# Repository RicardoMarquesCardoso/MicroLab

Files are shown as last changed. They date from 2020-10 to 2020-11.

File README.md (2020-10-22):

# MicroLab
The Microlab project describes how to build a simple and inexpensive system for the opperation of microfluidic devices. The system consists of four syringe pumps and a microscope. To opperate this peripherals, software was also developed. 

## System Overview 

<p align="center">
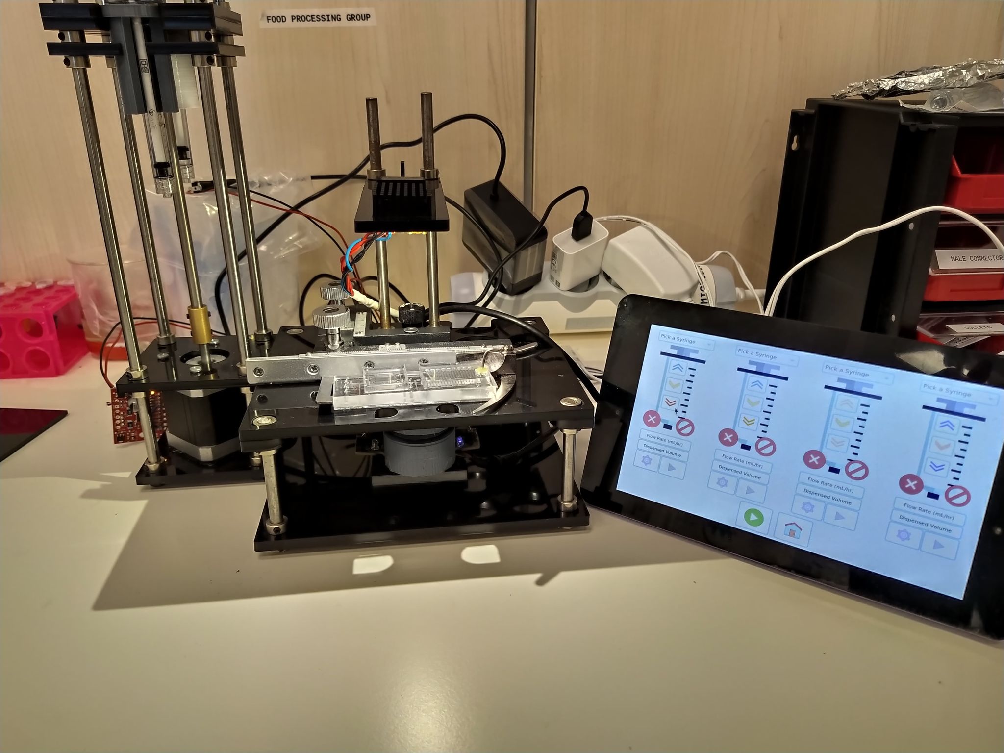
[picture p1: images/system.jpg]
  
</p>

The system consists of:
* [Syringe Pump](Microlab/SyringePump) 
* [Microscope](https://github.com/RicardoMarquesCardoso/MicroLab/tree/main/Microscope) 
* [Software](Microlab/Software) 

**The peripherals were developed using 3D printing techniques and laser cutting. Both methods are required in order to build the system**

## Contents

### Syringe Pump

* CAD drawings
* Bill of materials
* How to build 
* Microcontroller Code

### Microscope

* Bill of materials
* How to build 

### Software

* Raspberry Pi + Touchscreen
* How to install Windows, Mac, Linux
* Basic Guide

## About

This project was developed by me, Ricardo Cardoso, in collaboration with the International Iberian Nanotechnology Laboratory for my master thesis in Biomedical Engineering at the University of Porto .

This project is inspired in solutions developed by [Martin Fischlechner, Jonathan West and Klaus-Peter Zauner](https://dropletkitchen.github.io/pages/projects.html) and by [Patcherlab](https://pachterlab.github.io/poseidon/).

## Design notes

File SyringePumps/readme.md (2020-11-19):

# Syringe Pump

### Introduction

The goal is to develop a low-cost, easy to build syringe pump suitable for the operation of microfluidic devices. This solution is heavily influenced by the one presented by [DropletKitchen](https://github.com/DropletKitchen/pumpsn17). 

The developed syringe pumps tries to introduce two main features to the other available noncommercial solutions:

* Dispense two syringes with a single device;
* Possibility to operate in the vertical position;

Step resolution : 0.04 nm/µstep
Size : 7cm x 7cm x 30cm
Price : 110 €

<p align="center">
  
</p>

### Materials and tools

Besides all required [materials](#bill-of-materials), to replicate this project you will need access to a: 

* Laser Cutter machine;
* 3D printing machine; 
* Welding machine;

### About

This project was developed at the International Iberian Nanotechnology Laboratory by Ricardo Cardoso and supervised by Miguel Xavier,Ph.D. and researcher at INL. 
The main inspiration for this project was the [DropletKitchen's solution](https://dropletkitchen.github.io/index.html). Please go and review their project as a lot of information is complementary to this one!

## Stepper Motor + LeadScrew

## Driver

## Structure

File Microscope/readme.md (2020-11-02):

# Microscope

### Introduction

This describes a portable, low-cost, easy to build microscope suitable for the operation of microfluidic devices. 
The microscope consists of three main parts: 

* [Camera](#camera)
* [Light](#light)
* [Structure](#structure)

<p align="center">
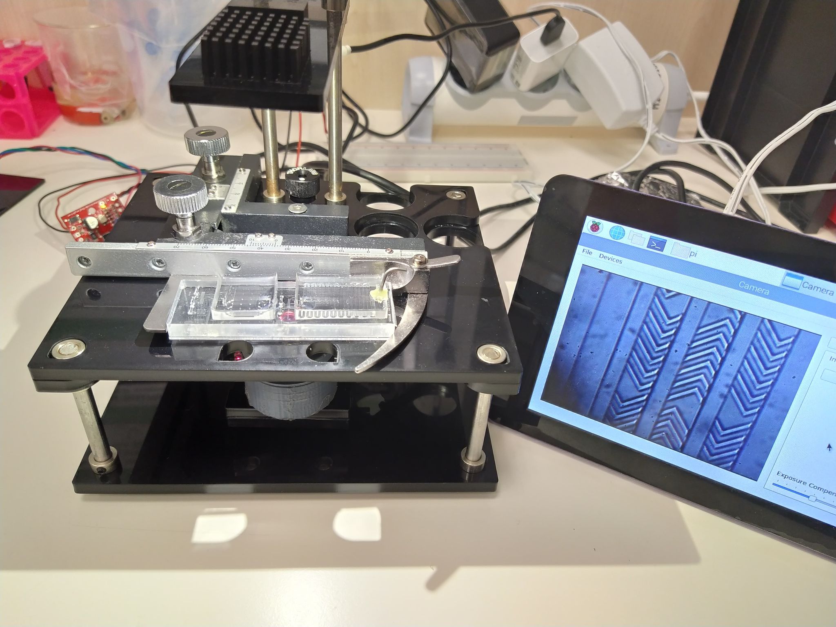
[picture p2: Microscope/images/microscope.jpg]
  
</p>

### Materials and tools

Besides all required [materials](#bill-of-materials), to replicate this project you will need access to a: 

* Laser Cutter machine;
* 3D printing machine; 
* Welding machine;

### About

This project was developed at the International Iberian Nanotechnology Laboratory by Ricardo Cardoso and supervised by Miguel Xavier,Ph.D. and researcher at INL. 
The main inspiration for this project was the [DropletKitchen's solution](https://dropletkitchen.github.io/index.html). Please go and review their project as a lot of information is complementary to this one!

## Camera

Shows you how to choose a suitable camera and how to alter it.

You will need some basic tools to take apart the camera and acess to a **3D printer**.

### Choosing a camera 

Based on previous studied open-source solutions, three main alternatives to a commercial microscope were identified: a USB microscope, a camera module or an altered webcam.
A few options were considered:

<p align="center">
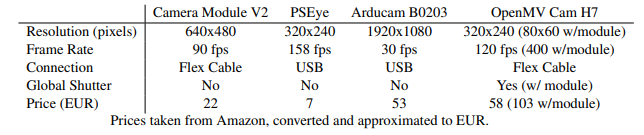
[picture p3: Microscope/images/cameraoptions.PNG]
  
</p>

The camera module OpenMV Cam H7 has a global shutter module that costs around 45 EUR.
Even though global shutter cameras are useful in some microfluidic applications, they are less available and have higher prices. More economical options exist such as the Sony 811 700TVL. However, instead of USB interface, these cameras have Analog High Definition (AHD) interface. The Raspberry Pi Camera Module V2 has interesting specs and a relatively low price; however the connection not being USB is a major disadvantage. The connection is made specifically for the Raspberry Pi through flat cable, which is not convenient for connecting and disconnecting regularly. Other camera modules exist, such as the Arducam B0203 that connect through USB; however they tend to be expensive.
For my requirements I chose the PlayStationEye camera for four main reasons: availability, cost, performance and connectivity. The main disadvantage is that additional drivers (CLEYE drivers and SDK) are required for the PS Eye to work on Windows, as well as for Mac OS.

### PSEye  

The PSEye fullfills all the requirements while being cheap and widely available. To transform this webcam into a microscope we need to simply invert the lens, going from concave to convex. An example on how to easily do this is found in [Hacketeria](https://www.hackteria.org/projects/ps3-eye-diy-microscopy-hack/). 

Two variables are essential for any basic microscope, focusing and zooming. Focusing is regulated by the distance between the lens and the sample, zooming by the distance between the lens and the CMOS. To allow for zooming, I designed a 3D printed part that allows the user to change the distance of the lens to the CMOS ([Part1](https://github.com/RicardoMarquesCardoso/MicroLab/blob/main/Microscope/Parts/%5BPSeye%5D%201.SLDPRT);[Part2](https://github.com/RicardoMarquesCardoso/MicroLab/blob/main/Microscope/Parts/%5BPSeye%5D%202.SLDPRT)). 

**Missing pic of finished part**

## Light

An independent circuit is responsible for illumination. One of the requirements for this microscope was that it should produce quality images even in total darkness. As so, a high-power LED was incorporated into the device. 

You will need:

* [LED](https://pt.farnell.com/opulent/rebel-star-nw100/led-luxeon-rebel-star-nw100/dp/2115404);
* [LED Driver](https://www.digikey.pt/product-detail/en/recom-power/RCD-24-0.70-W/945-1125-ND/2256305);
* [Potentiometer (10kOhm)](https://www.amazon.com/Slide-Potentiometer-Single-Linear-Taper/dp/B00L9YDRU6);
* Wires;
* Welding machine;
* Male USB connector;

The circuit is very simple and it should take less than an hour to build. I advise you to check if the circuit is working (without welding) before mounting it onto the microscope structure. 

<p align="center">
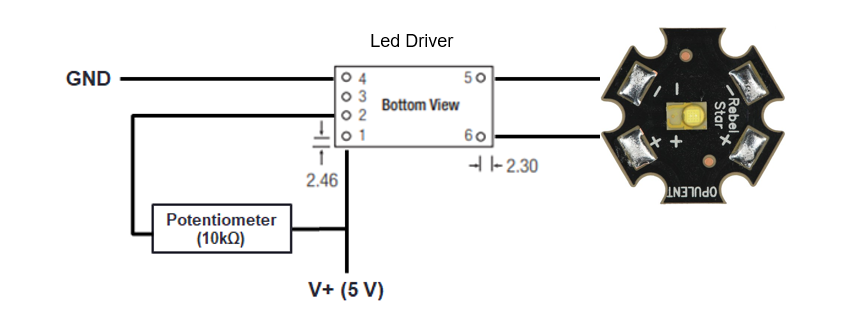
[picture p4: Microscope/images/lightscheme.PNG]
  
</p>

To simplify the powering of the circuit, a male USB connector is added to the end of the circuit. This allows the microscope to be powered by a common powerbank, avoiding the need for another electrical outlet and making the microscope portable.

<p align="center">
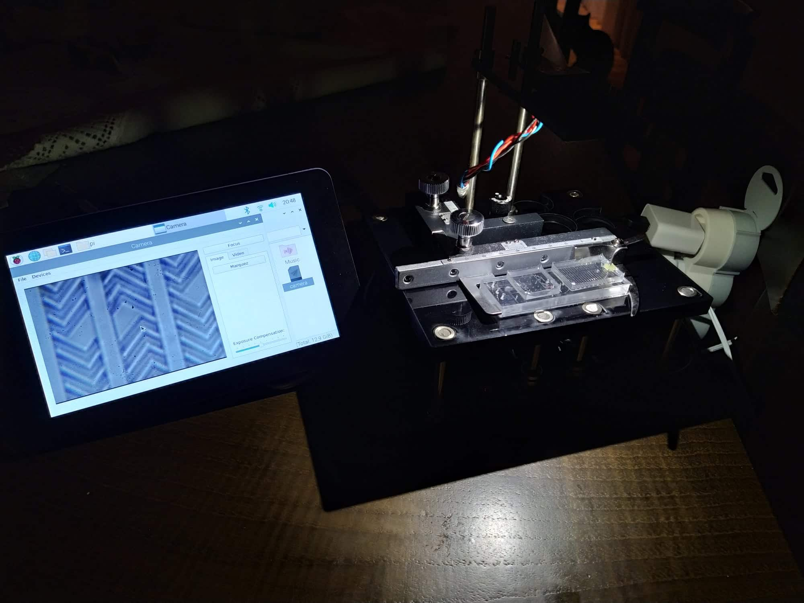
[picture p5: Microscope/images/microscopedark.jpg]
  
</p>

**Missing pic of finished part**

## Structure

You will need:

* 1x A3 Acrylic sheets (5mm);
* 4x Steel Bar 6x70 mm;
* 2x Steel Bar 6x130 mm;
* 30x Collets 6mm;
* Laser Cutter;

Before cutting any piece in acrylic [check](https://github.com/RicardoMarquesCardoso/MicroLab/tree/main/Microscope/Parts) the measurements and test them with your machine setup. 

If it's the first time building the device I would suggest to print each part separately. 

### Step 1

1. Print the two top parts of the microscope ([Part1](https://github.com/RicardoMarquesCardoso/MicroLab/blob/main/Microscope/Designs/%5BTop%5DPart1.DXF),[Part2](https://github.com/RicardoMarquesCardoso/MicroLab/blob/main/Microscope/Designs/%5BTop%5DPart2.DXF)
2. Glue them together using double sided tape.
3. Place a collet in the tip of each 6x70mm steel bar and slide them into the respective holes. Then using another collet pin the steel bars. 
4. Screw the microscope stage in place.

<p align="center">
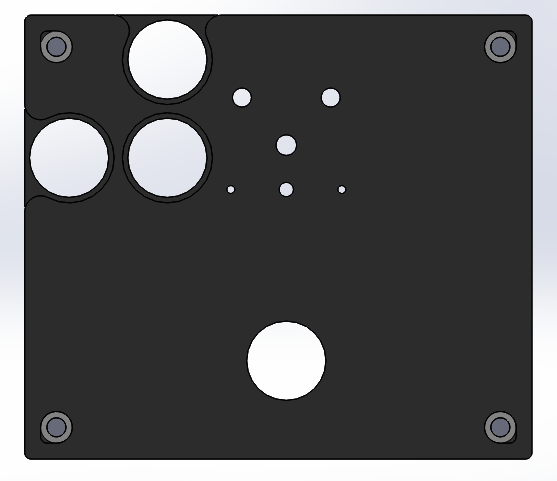
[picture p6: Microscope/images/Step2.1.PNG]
  
</p>

<p align="center">
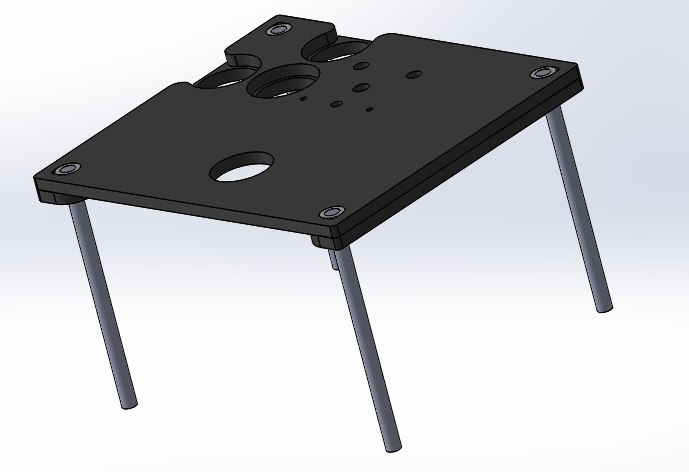
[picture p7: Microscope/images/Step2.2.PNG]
  
</p>

### Step 2

1. Print the parts that will hold the camera ([Top1](https://github.com/RicardoMarquesCardoso/MicroLab/blob/main/Microscope/Designs/%5BMovingPiece%5DTop1.DXF),[Top2](https://github.com/RicardoMarquesCardoso/MicroLab/blob/main/Microscope/Designs/%5BMovingPiece%5DTop2.DXF),[Bottom](https://github.com/RicardoMarquesCardoso/MicroLab/blob/main/Microscope/Designs/%5BMovingPiece%5DBottom.DXF))
2. Glue the top parts to the bottom using double sided tape.
3. Put the linear bearings into the respective holes. They should be very tight to impossibilitate the acrylic from sliding.
4. Screw the modified PSEye in place. 
5. Place the nut and the screw.
6. With the microscope in upright position place the 2 support bars and pin them in place. 
7. Place the mounted camera part into place.

<p align="center">
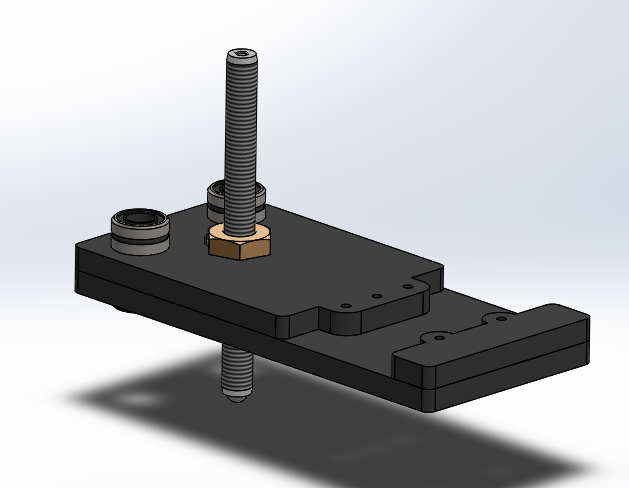
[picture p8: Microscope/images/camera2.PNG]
  
</p>

<p align="center">
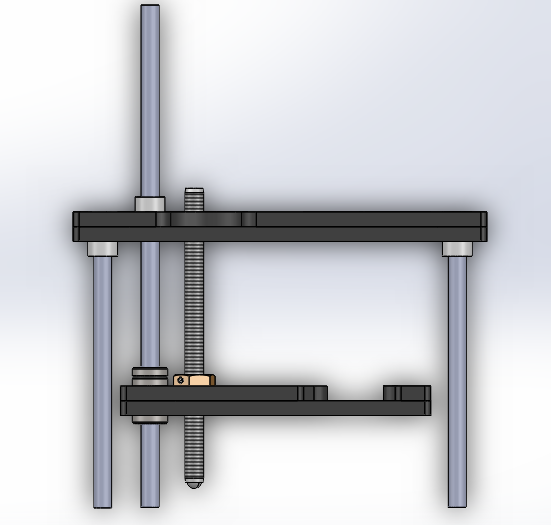
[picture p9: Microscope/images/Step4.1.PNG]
  
</p>

### Step 3

1. Print and place the bottom part and LED parts.

<p align="center">
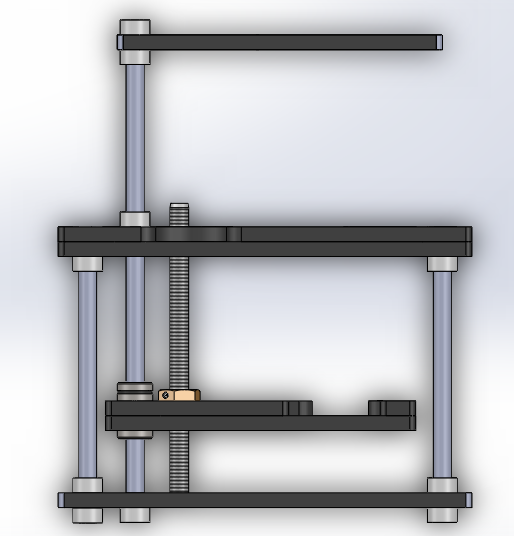
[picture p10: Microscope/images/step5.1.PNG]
  
</p>

## Results

<p align="center">
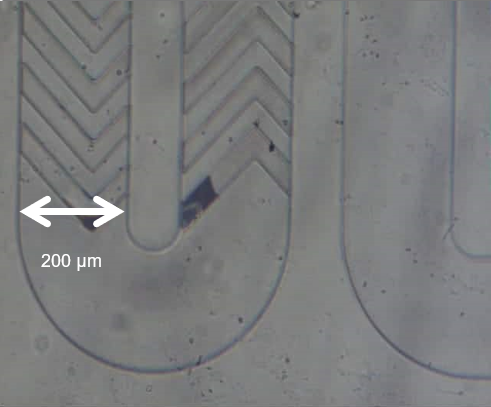
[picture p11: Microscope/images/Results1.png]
  
</p>

## Bill of materials 

<p align="center">
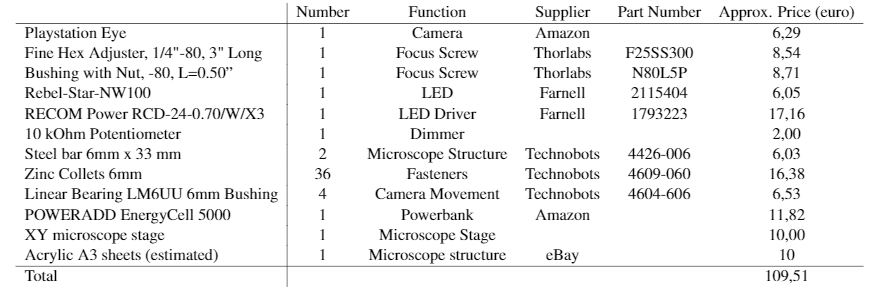
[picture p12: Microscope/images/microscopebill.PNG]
  
</p>

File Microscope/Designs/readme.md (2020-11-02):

# Microscope Parts

**Before cutting any piece in acrylic check the measurements and test them with your machine setup.**

To easy the proccess, each 'hole' in the acrylic is highlighted with a certain color:

- #c5f015- Measurements that don't need much attention;
- #1589F0- Measurements that need some checking since some precision is required;
- #f03c15- Measurements that need to be thoroughly checked, a lot of precision is required;

## Top 

<p align="center">
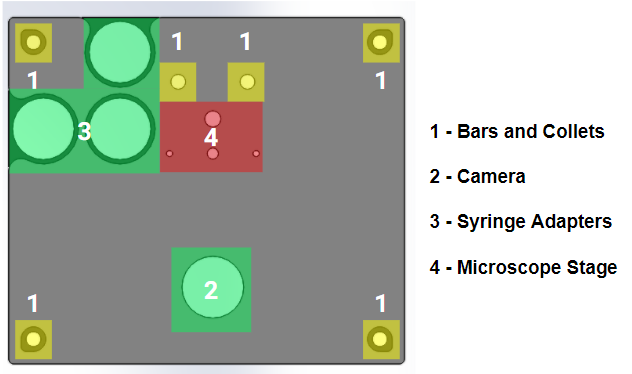
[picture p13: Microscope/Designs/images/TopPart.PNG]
  
</p>

**Keep in mind that your microscope stage may be different**

## Bottom

<p align="center">
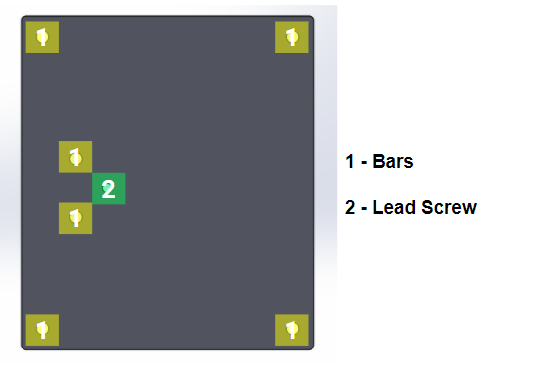
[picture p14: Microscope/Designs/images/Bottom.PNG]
  
</p>

**Lead Screw hold should be smaller than the point of the lead screw.** 

## Light 

<p align="center">
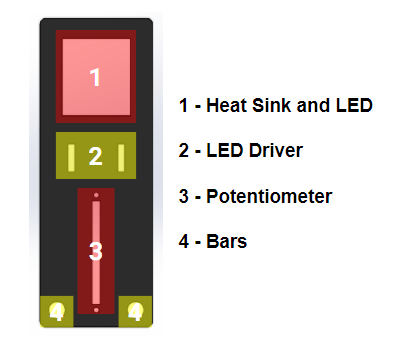
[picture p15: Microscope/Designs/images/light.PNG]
  
</p>

**Put each component in the respective place and then weld the circuit.**

## Camera

<p align="center">
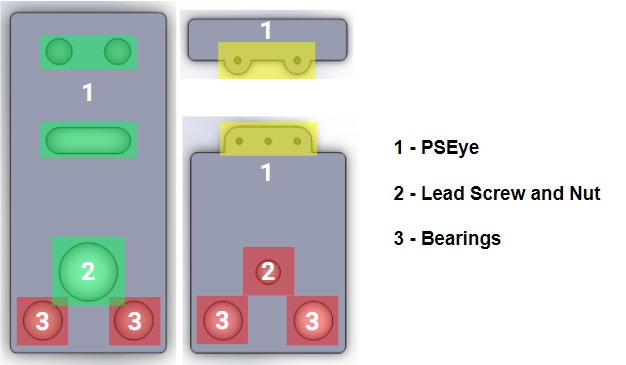
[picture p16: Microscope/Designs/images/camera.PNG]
  
</p>

**This is designed to hold a PSEYE, if you chose a different camera please alter the respective dimensions.**

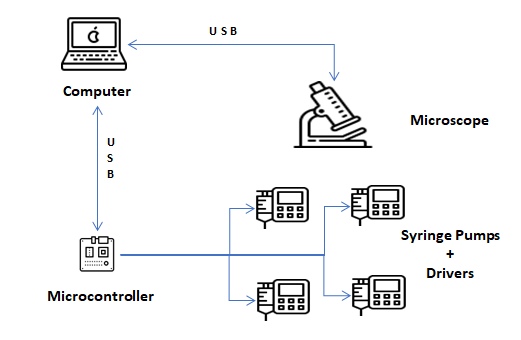
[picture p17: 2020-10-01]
images/overallsystem2.PNG

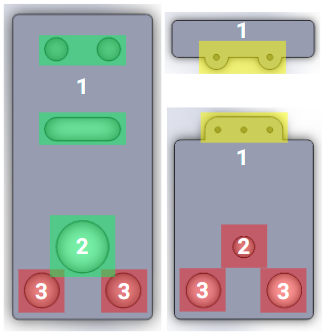
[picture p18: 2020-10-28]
Microscope/images/movingpart.PNG

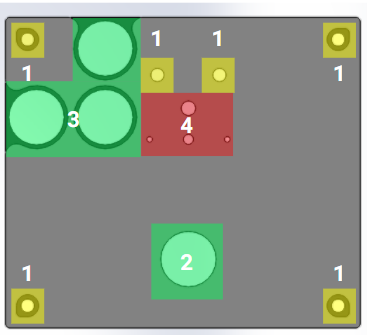
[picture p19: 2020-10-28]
Microscope/images/TopPart.PNG

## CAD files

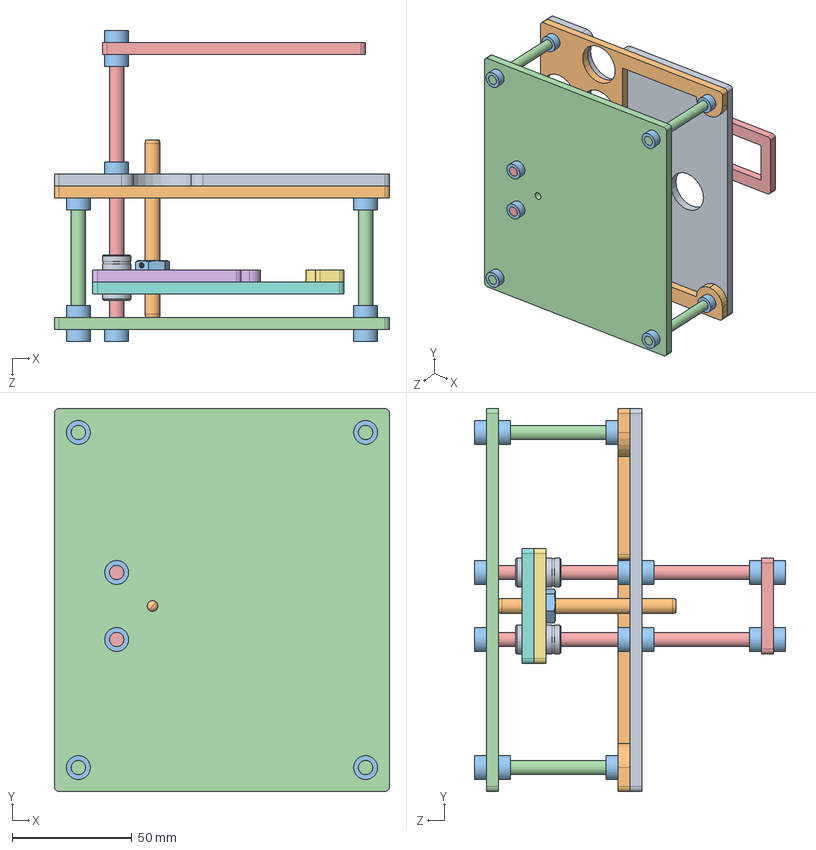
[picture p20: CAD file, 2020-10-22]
Microscope/Parts/Microscope.SLDASM
140.0 x 160.0 x 130.0 mm
[Top] Part1
[Top] Part2
Collets x 27
Bar7cm x 4
Bar13cm x 2
[MovingPiece] top1
[MovingPiece] top2
[MovingPiece] bottom
Bearing (LM6UU) x 2
Screw (F25SS300)
Nut (N80L5P)
BottomPart
Light

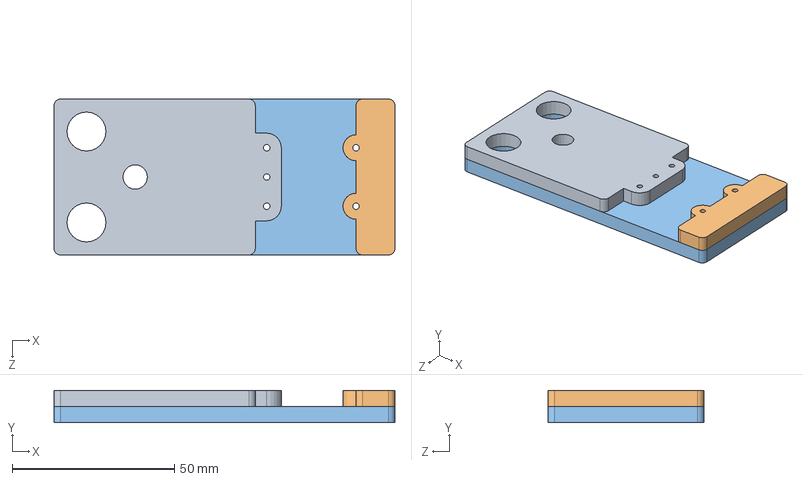
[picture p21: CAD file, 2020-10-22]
Microscope/Parts/[MovingPiece]Assembly.SLDASM
105.0 x 10.0 x 48.0 mm
[MovingPiece] top1
[MovingPiece] top2
[MovingPiece] bottom

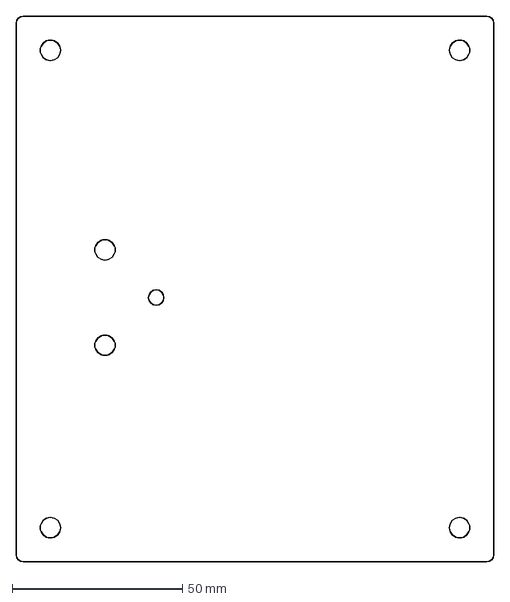
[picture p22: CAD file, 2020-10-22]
Microscope/Designs/BottomPart.DXF
140.0 x 160.0 mm

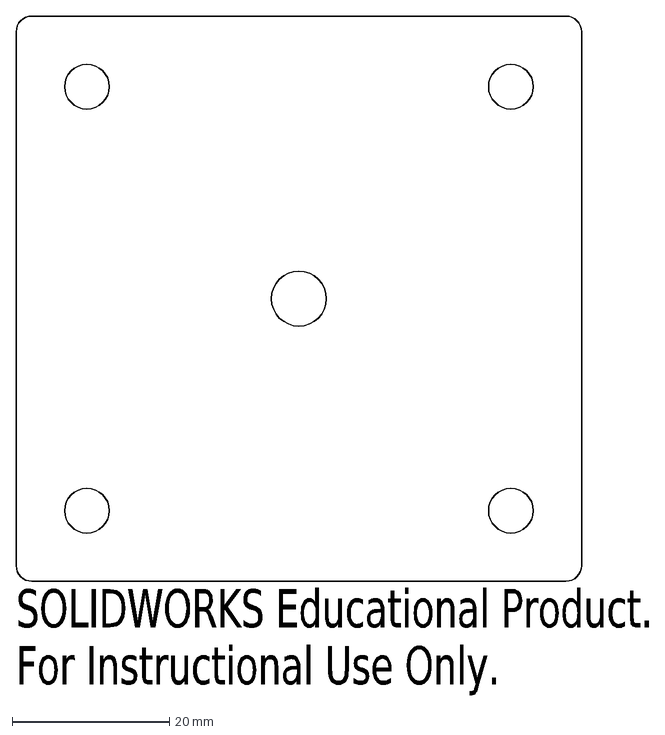
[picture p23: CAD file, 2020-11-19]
SyringePumps/Designs/TopCover.DXF
SOLIDWORKS Educational Product.
For Instructional Use Only.

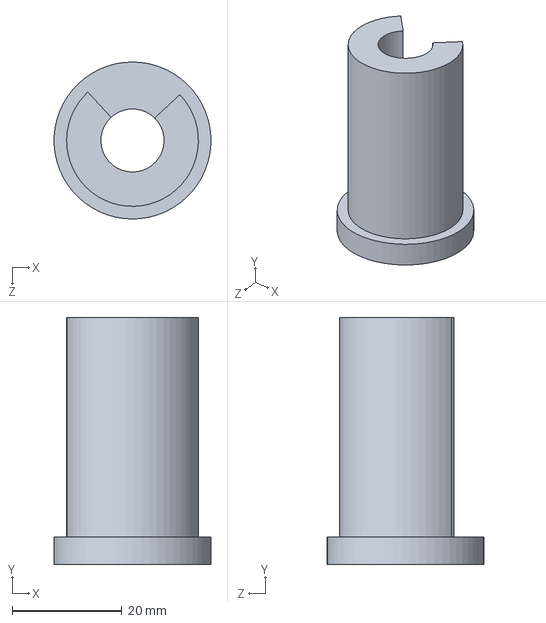
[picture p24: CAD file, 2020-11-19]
SyringePumps/Parts/Adapters/11.5mm.SLDPRT
28.6 x 45.0 x 28.6 mm

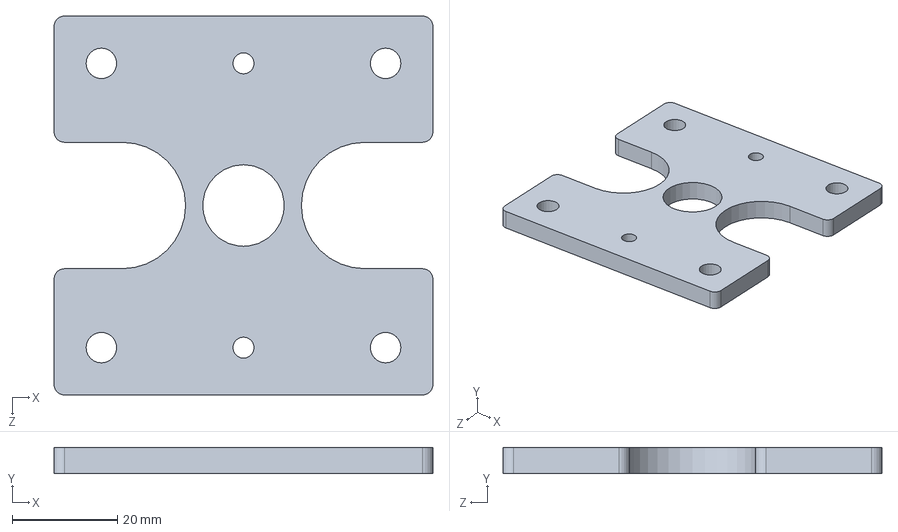
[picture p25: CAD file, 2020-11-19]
SyringePumps/Parts/Syringeholder2.SLDPRT
72.0 x 5.00 x 72.0 mm

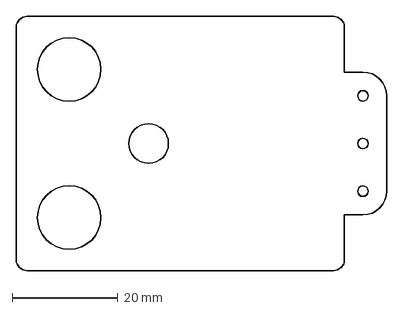
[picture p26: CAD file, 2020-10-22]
Microscope/Designs/[MovingPiece]Top1.DXF
70.0 x 48.0 mm

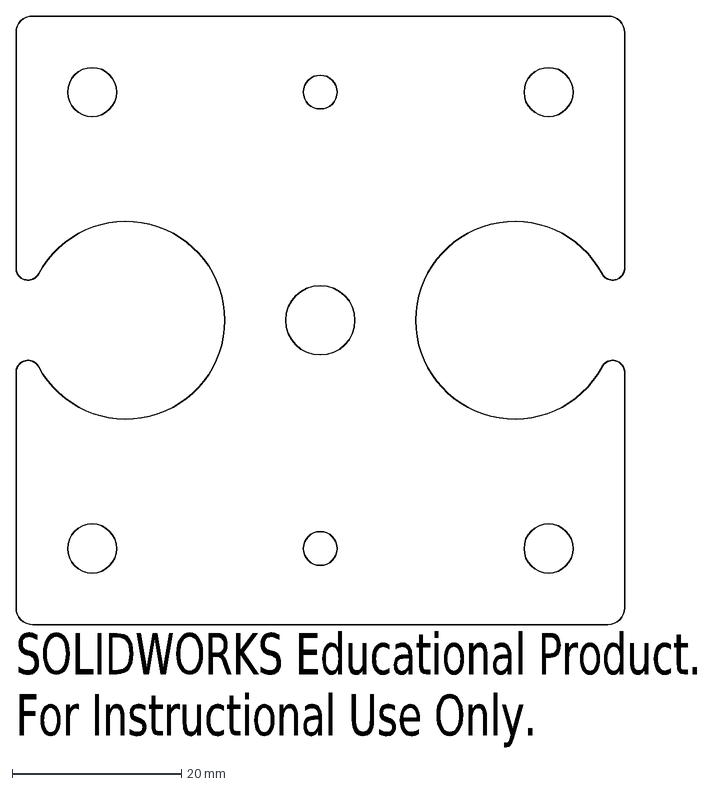
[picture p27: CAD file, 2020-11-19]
SyringePumps/Designs/syringeholder3.DXF
SOLIDWORKS Educational Product.
For Instructional Use Only.

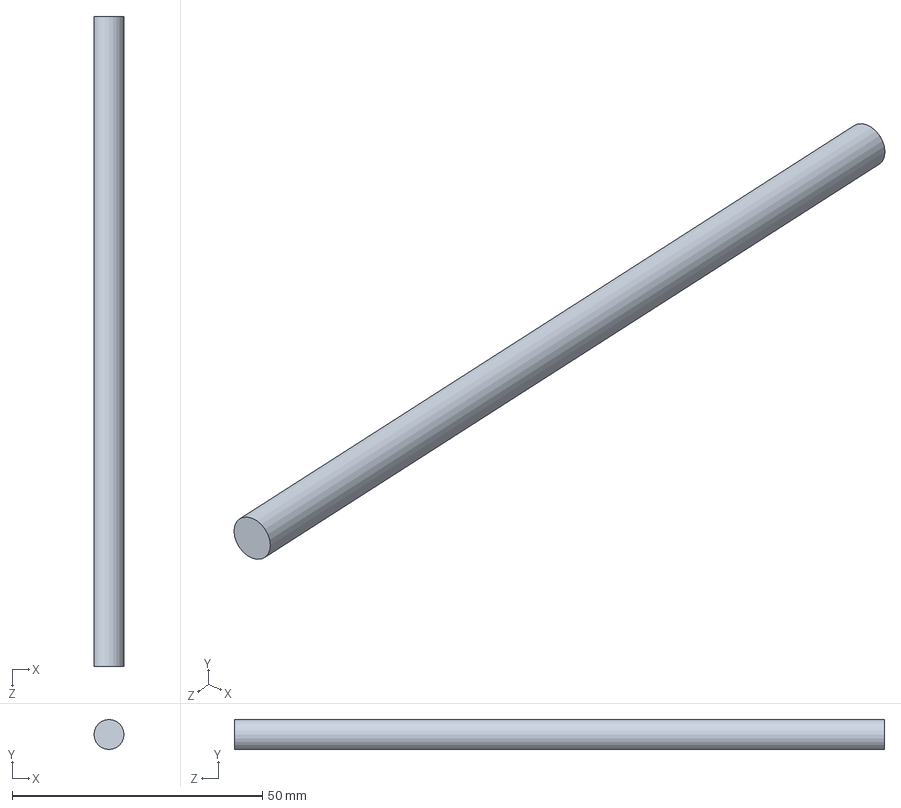
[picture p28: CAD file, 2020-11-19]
SyringePumps/Parts/bar(13cm).SLDPRT
6.00 x 6.00 x 130.0 mm

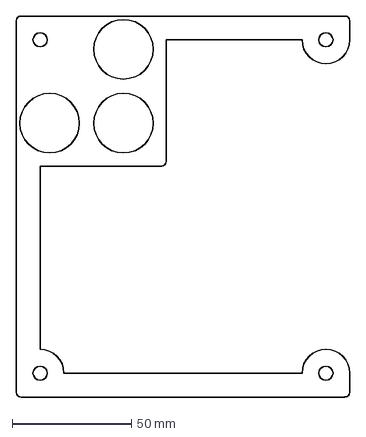
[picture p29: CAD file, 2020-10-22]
Microscope/Designs/[Top]Part2.DXF
140.0 x 160.0 mm

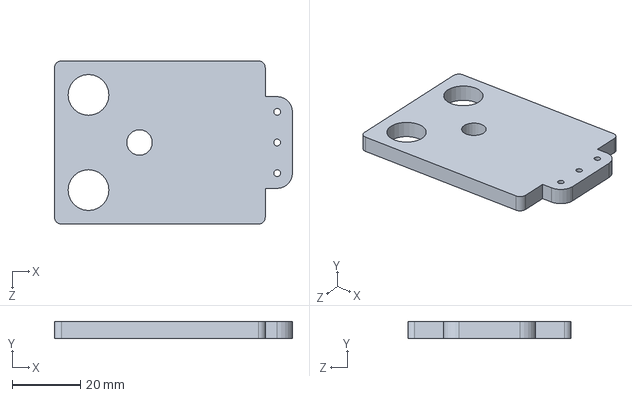
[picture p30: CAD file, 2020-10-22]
Microscope/Parts/[MovingPiece]Top1.SLDPRT
70.0 x 5.00 x 48.0 mm

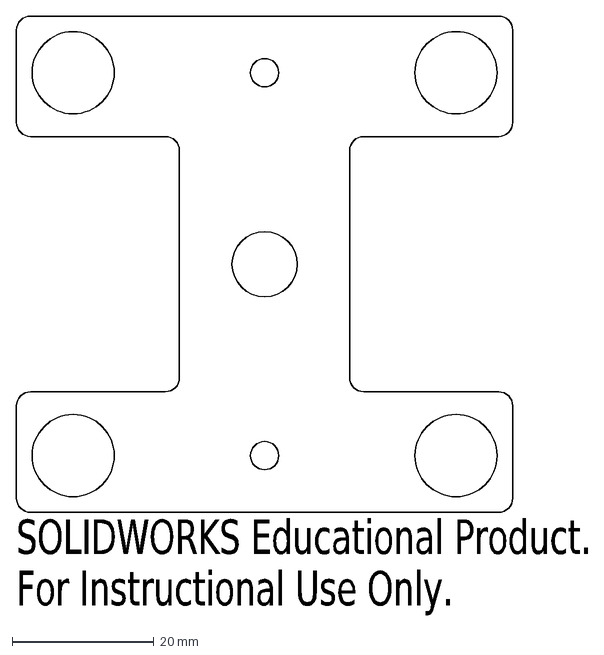
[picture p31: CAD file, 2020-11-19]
SyringePumps/Designs/movingpart2.DXF
SOLIDWORKS Educational Product.
For Instructional Use Only.

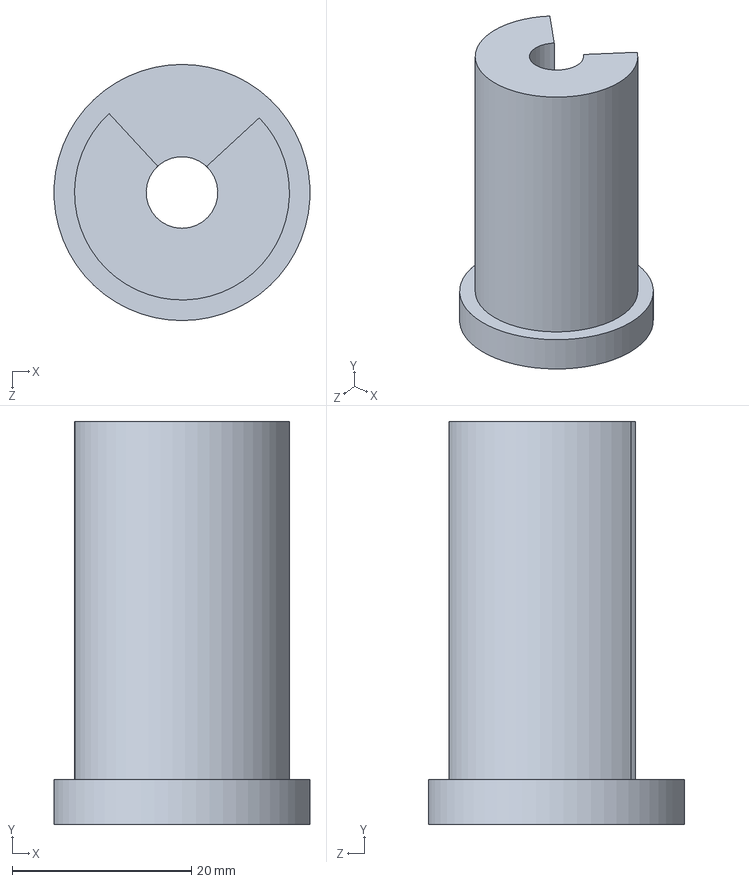
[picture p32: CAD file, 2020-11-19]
SyringePumps/Parts/Adapters/8mm.SLDPRT
28.6 x 45.0 x 28.6 mm

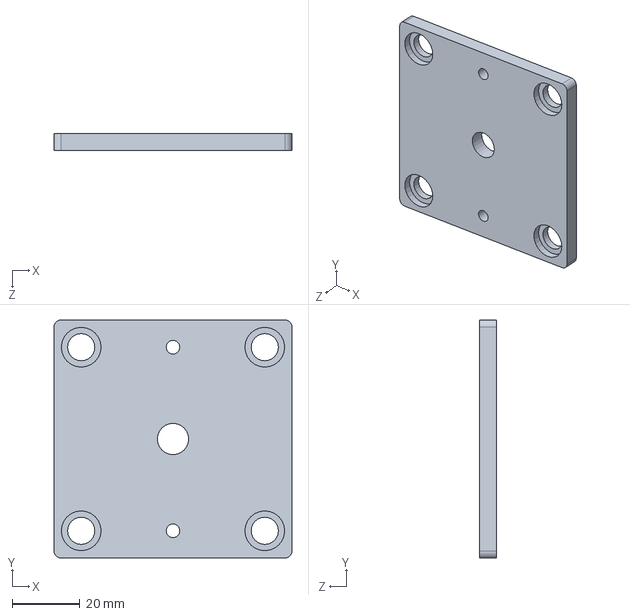
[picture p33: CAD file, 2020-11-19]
SyringePumps/Parts/movingpart - Cover.SLDPRT
70.0 x 70.0 x 5.00 mm

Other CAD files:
SyringePumps/Parts/Adapters/11mm.STL
Microscope/Designs/[Top]Part1.DXF
SyringePumps/Designs/Syringeholder2.DXF
SyringePumps/Parts/Adapters/18mm.SLDPRT
Microscope/Designs/Light.DXF
Microscope/Designs/[MovingPiece]Bottom.DXF
Microscope/Designs/[MovingPiece]Top2.DXF
Microscope/Parts/Bar13cm.SLDPRT
Microscope/Parts/Bar7cm.SLDPRT
Microscope/Parts/Bearing(LM6UU).SLDPRT
Microscope/Parts/BottomPart.SLDPRT
Microscope/Parts/Collets.SLDPRT
Microscope/Parts/Light.SLDPRT
Microscope/Parts/Nut(N80L5P).sldprt
Microscope/Parts/Screw(F25SS300).sldprt
Microscope/Parts/[MovingPiece]Bottom.SLDPRT
Microscope/Parts/[MovingPiece]Top2.SLDPRT
Microscope/Parts/[PSeye]Part1.SLDPRT
Microscope/Parts/[PSeye]Part2.SLDPRT
Microscope/Parts/[Top]Part1.SLDPRT
Microscope/Parts/[Top]Part2.SLDPRT
SyringePumps/Designs/MotorTop.DXF
SyringePumps/Designs/Syringeholder1.DXF
SyringePumps/Designs/movingpart.DXF
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
